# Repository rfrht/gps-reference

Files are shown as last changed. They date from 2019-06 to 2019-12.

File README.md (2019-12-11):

# GPS-Referenced Programmable Precision Signal Generator

**Current state:** Board built and operational! However, you will want to check [Issues](https://github.com/rfrht/gps-reference/issues)

**Next steps:** Fix issues and release a [Revision B](https://github.com/rfrht/gps-reference/tree/Experimental) - Already WIP.

## Overview

This is the do-it-yourself version of the u-Blox-based **GPS-Referenced Programmable Precision Signal Generator**.

The board design is largely inspired by [ZL2PD design](https://www.zl2pd.com/GPS_Freq_Ref.html) and features a few other stuff, like break-out headers for I2C, Serial, USB, External Battery and antenna selector. There are two signal outputs; one [DC-coupled (0-3.3V)](https://rf3.org:8443/q/gps/gps-ref-1-mhz.png), suitable for logic level output and an [AC-coupled (-1.6V - 1.6V)](https://rf3.org:8443/q/gps/gps-ref-dc-1-hz.png) output.

RA3APW [did some some extensive research (Russian content)](http://www.ra3apw.ru/proekty/ublox-neo-7m/) and found that there are a few frequencies where there is some very good precision for the general hobbyist, yielding precision between 0.1 PPM to 1 PPB. This is not a [GPS-Disciplined Oscillator](https://en.wikipedia.org/wiki/GPS_disciplined_oscillator) but a high precision [Numerically Controlled Oscillator](https://en.wikipedia.org/wiki/Numerically_controlled_oscillator) instead.

Bear in mind that the RA3APW tested U-Blox M-7 hardware, while in this project we will be using the newer generation [NEO-M8Q-01A Automotive grade](https://www.u-blox.com/en/product/neo-m8q-01a-module), which sports a [TCXO](https://en.wikipedia.org/wiki/Crystal_oscillator#Temperature), (hopefully) increasing precision.

## Frequencies

The tested high reliability frequencies are, namely:

| Frequency | Frequency |
| --- | --- |
| [300 kHz](https://rf3.org:8443/q/gps/gps-ref-300-khz.png) | [500 kHz](https://rf3.org:8443/q/gps/gps-ref-500-khz.png) |
| [1 MHz](https://rf3.org:8443/q/gps/gps-ref-1-mhz.png) | [1.2 MHz](https://rf3.org:8443/q/gps/gps-ref-1-2-mhz.png) |
| [1.5 MHz](https://rf3.org:8443/q/gps/gps-ref-1-5-mhz.png) | [1.6 MHz](https://rf3.org:8443/q/gps/gps-ref-1-6-mhz.png) |
| [2 MHz](https://rf3.org:8443/q/gps/gps-ref-2-mhz.png) | [2.4 MHz](https://rf3.org:8443/q/gps/gps-ref-2-4-mhz.png) |
| [3 MHz](https://rf3.org:8443/q/gps/gps-ref-3-mhz.png) | [4 MHz](https://rf3.org:8443/q/gps/gps-ref-4-mhz.png) |
| [4.8 MHz](https://rf3.org:8443/q/gps/gps-ref-4-8-mhz.png) | [6 MHz](https://rf3.org:8443/q/gps/gps-ref-6-mhz.png) |
| [8 MHz](https://rf3.org:8443/q/gps/gps-ref-8-mhz.png) | [12 MHz](https://rf3.org:8443/q/gps/gps-ref-12-mhz.png) |
| [24 MHz](https://rf3.org:8443/q/gps/gps-ref-24-mhz.png) | --- |

There are certainly others. It seem to follow some mathematical order, but I failed to figure out the proper sequence.

### Good frequency waveform
This is a 1 MHz waveform:

1 MHz GPS-Referenced signal

### Non-optimal frequencies
Check this 16 MHz signal, there are harmonics along the main waveform:

16 MHz unsuitable waveform

This is how the problem manifests in low frequencies. Check the falling edge of a 360 kHz:

360 kHz signal

## Configuration
Use the [U-Blox U-Center](https://www.u-blox.com/en/product/u-center) tool to configure your board. Open the Config page, in `TP5 (Timepulse 5)` menu and configure as per the below screenshot:

U-Blox Signal Generator configuration

*U-Blox Configuration page - Click to enlarge*

## Artefacts

The [schematics](/Schematics) are in Autodesk Eagle CAD format.

There is a [Gerber](https://github.com/rfrht/gps-reference/raw/master/Design/gps-gerbers.zip) for ordering a PCB from your favourite PCB shop (Hint: $2 in jlcpcb.com for 5 units), as well a Digi-Key friendly [Bill of Materials](/Design/gps-bom.csv), which currently costs around $27 (including the GPS module).

## Board pictures:
Board:

Board front

Cabled (with external wire antenna):
Cabled GPS Referenced Board

## TODO:
Check [Issues](https://github.com/rfrht/gps-reference/issues)

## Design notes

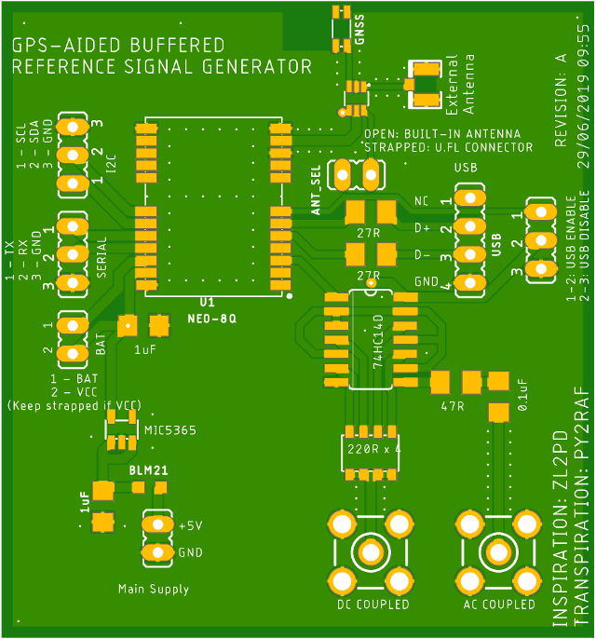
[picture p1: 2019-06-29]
Design/gps-top.png

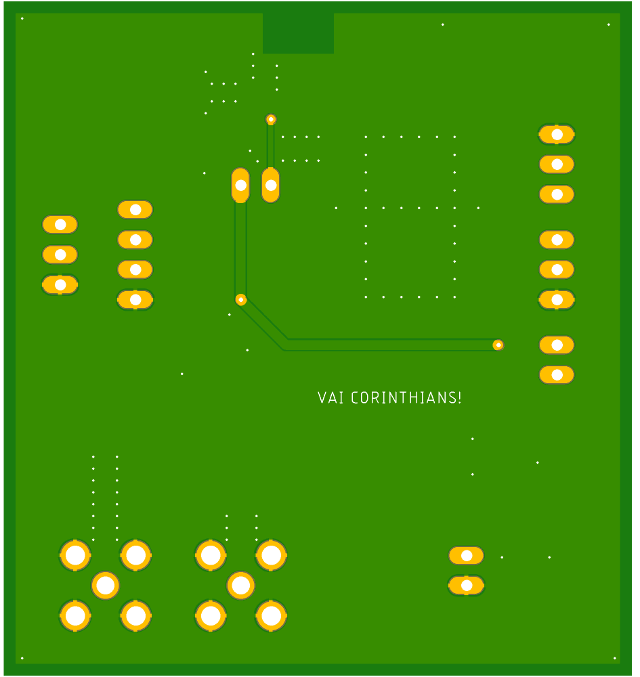
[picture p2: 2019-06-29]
Design/gps-bottom.png

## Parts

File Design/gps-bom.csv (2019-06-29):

Qty | Value | Device | Package | Parts | Digi-Key PN
1 | 0.1uF | C-EUC1206 | 1206 | C1 | 732-8086-1-ND
2 | 1uF | C-EUC1206 | 1206 | C2, C3 | 732-7685-1-ND
1 | 74HC14D | 74HC14D | SO14 | IC1 | 1727-1029-1-ND
1 | +5V | JP1E | JP1 | JP7 | S1012EC-40-ND
1 | BLM21 | L-USL2012C | L2012C | L1 | 490-1041-1-ND
1 | PE4259 | PE4259 | SC-70 | Q1 | 1046-1011-1-ND
1 | MIC5365 | MIC5365 | SOT23-5L | Q2 | 576-4085-1-ND
1 | 744C083 | 744C083 | 1206X4 | R1 | 744C083221JPCT-ND
1 | 47R | R-US_M1206 | 1206 | R2 | CR1206-FX-47R0ELFCT-ND
2 | 27R | R-US_M1206 | 1206 | R3, R4 | RHM27CJCT-ND
1 | NEO-8Q | NEO-8 | NEO | U1 | 672-1174-1-ND
2 | REF_DC | SMA-PCB | SMA-RF | X1, X2 | A97594-ND
1 | GNSS | ANT-GNSS-MLX | MOLEX-GNSS | X3 | WM16803CT-ND
1 | Ext Ant | ANTENNA_U.FL | U.FL | X4 | A118077CT-ND

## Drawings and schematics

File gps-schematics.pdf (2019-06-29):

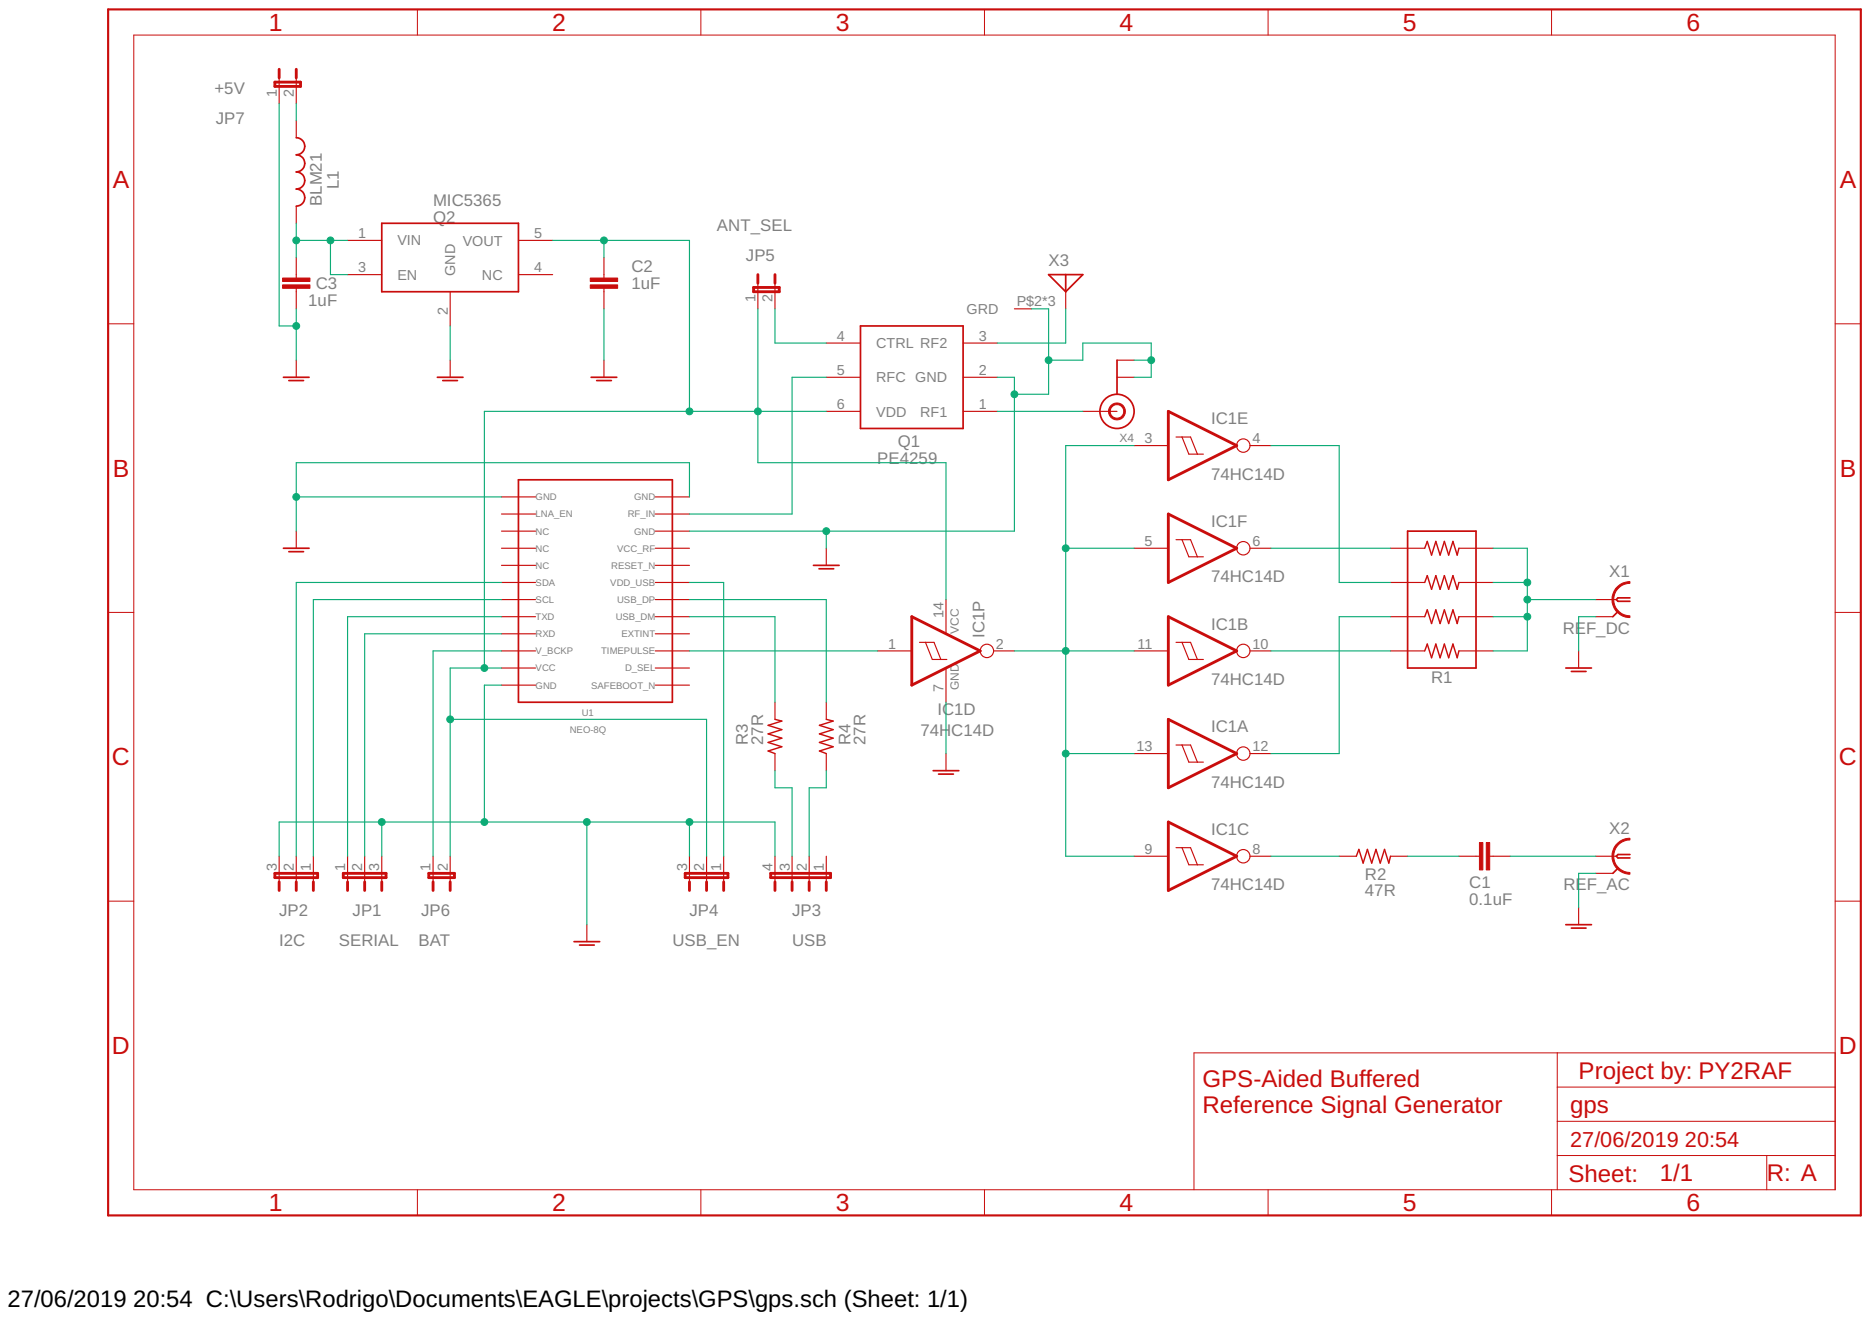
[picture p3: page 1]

27/06/2019 20:54 C:\Users\Rodrigo\Documents\EAGLE\projects\GPS\gps.sch (Sheet: 1/1)

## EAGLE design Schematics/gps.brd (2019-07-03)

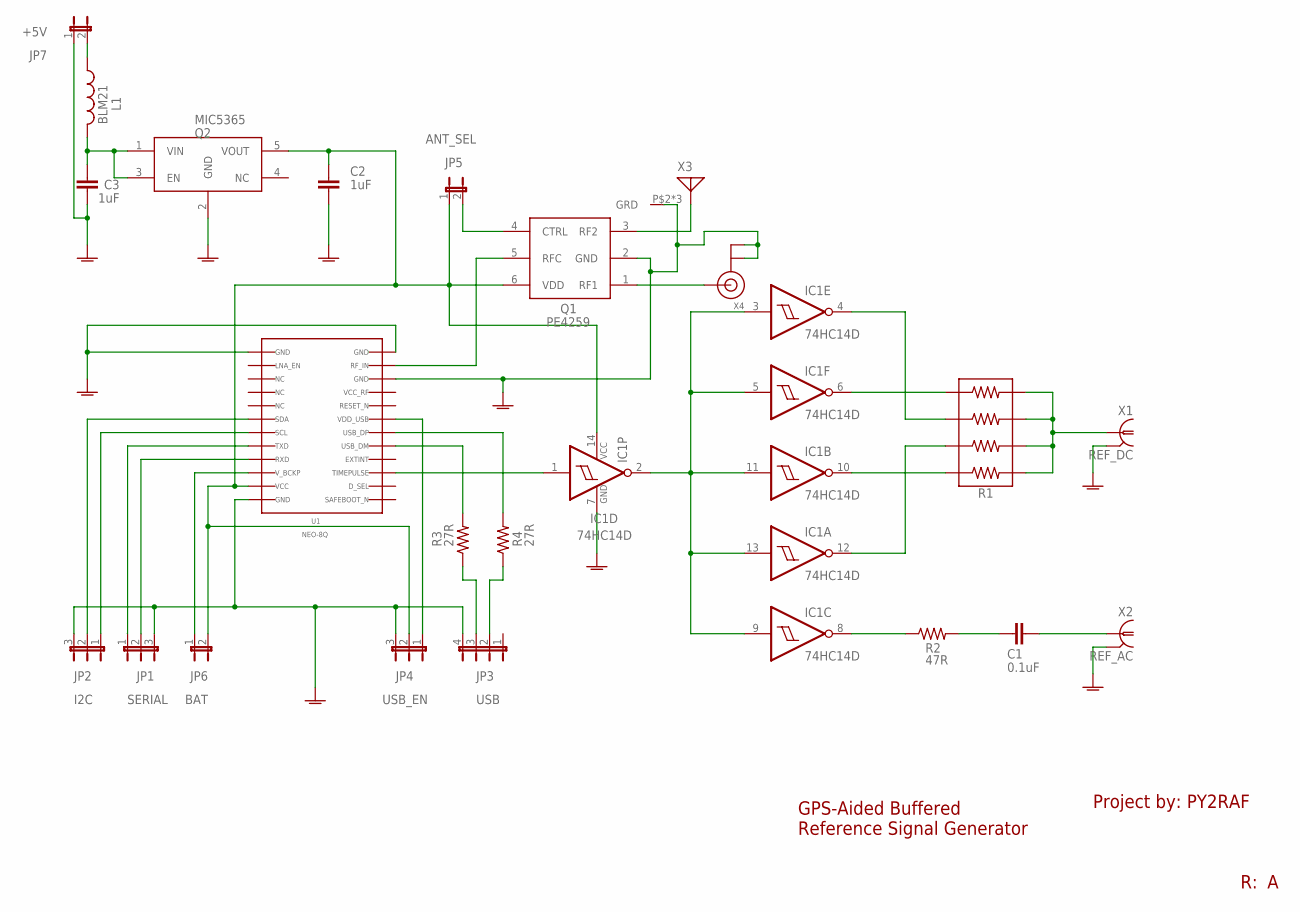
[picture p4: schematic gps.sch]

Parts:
C1: 0.1uF; C1206
C2, C3: 1uF; C1206
IC1: 74HC14D; SO14
JP1: SERIAL; JP2
JP2: I2C; JP2
JP3: USB; JP4
JP4: USB_EN; JP2
JP5: ANT_SEL; JP1
JP6: BAT; JP1
JP7: +5V; JP1
L1: BLM21; L2012C
Q1: PE4259; SC-70
Q2: MIC5365; SOT23-5L
R1: 744C083; 1206X4
R2: 47R; M1206
R3, R4: 27R; M1206
U1: NEO-8Q; NEO-7
X1: REF_DC; SMA-RF
X2: REF_AC; SMA-RF
X3: ANT-GNSS-MLX; MOLEX-GNSS
X4: ANTENNA_U.FL; U.FL

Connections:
GNDA: C2.2, C3.2, IC1.7 (GND), JP1.3, JP2.3, JP3.4, JP4.3, JP7.1, Q1.2 (GND), Q2.2 (GND), U1.10, U1.12, U1.13, U1.24, X1.2, X1.3 (2), X1.4 (2), X1.5 (2), X2.2, X2.3 (2), X2.4 (2), X2.5 (2), X3.P$2 (GRD), X3.P$3 (GRD), X3.P$4 (GRD), X4.1 (GND), X4.2 (GND)
unnamed: IC1.2 (O), IC1.3 (I), IC1.5 (I), IC1.9 (I), IC1.11 (I), IC1.13 (I)
unnamed: IC1.4 (O), R1.P$3 (3)
unnamed: IC1.12 (O), R1.P$2 (2)
unnamed: IC1.10 (O), R1.P$1 (1)
unnamed: IC1.6 (O), R1.P$4 (4)
unnamed: IC1.1 (I), U1.3
unnamed: IC1.8 (O), R2.1
unnamed: C1.2, R2.2
unnamed: R3.2, U1.5
unnamed: R4.2, U1.6
unnamed: C1.1, X2.1
unnamed: JP4.1, U1.7
unnamed: JP3.3, R3.1
unnamed: JP3.2, R4.1
unnamed: JP2.2, U1.18
unnamed: JP2.1, U1.19
unnamed: JP1.2, U1.21
unnamed: JP1.1, U1.20
unnamed: JP6.1, U1.22
unnamed: JP5.2, Q1.4 (CTRL)
unnamed: R1.P$5 (5), R1.P$6 (6), R1.P$7 (7), R1.P$8 (8), X1.1
unnamed: C2.1, IC1.14 (VCC), JP4.2, JP5.1, JP6.2, Q1.6 (VDD), Q2.5 (VOUT), U1.23
unnamed: Q1.5 (RFC), U1.11
unnamed: C3.1, L1.2, Q2.1 (VIN), Q2.3 (EN)
unnamed: JP7.2, L1.1
unnamed: Q1.3 (RF2), X3.P$1 (ANT)
unnamed: Q1.1 (RF1), X4.3 (SIGNAL)

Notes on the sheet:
GPS-Aided Buffered Reference Signal Generator
Project by:

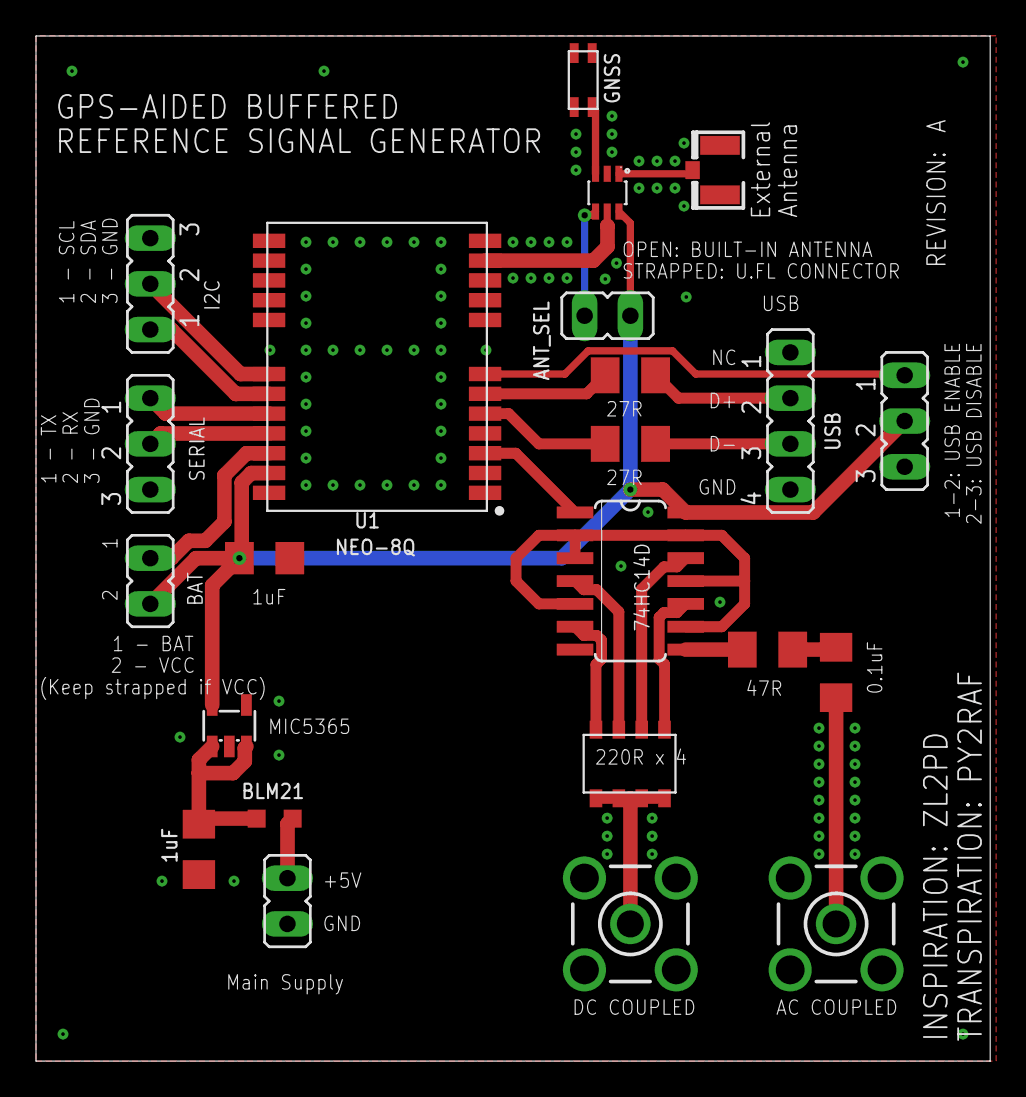
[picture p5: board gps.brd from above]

Board: 2 copper layers, 53.0 x 57.0 mm, 23 parts (0 on the bottom side), 28 nets.

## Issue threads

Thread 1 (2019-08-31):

Wrong antenna solder pad

rfrht, 2019-08-31:
**ISSUE**
The antenna solder pad is PLAIN WRONG.

**ENVIRONMENT**

**SOLUTION**
The definitive solution will involve a new board revision with the corrected solder pad
As a workaround, use the U.FL connector.

rfrht, 2019-12-10:
Fixed in Rev. B

Closed 2019-12-10.

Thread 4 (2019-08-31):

Make a switchable USB powering

rfrht, 2019-08-31:
Currently, the +5V from USB cable ends in a N/C lead.

Connect this lead to a jumper switch selecting the board power.

rfrht, 2019-12-10:
Implemented in Rev. B

Closed 2019-12-10.

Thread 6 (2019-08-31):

Add a frequency LED

rfrht, 2019-08-31:

rfrht, 2019-12-10:
Not happening - The GPS signal is fed to the Clock generator and I don't want to disturb the signal potentially adding jittery.

Closed 2019-12-10.

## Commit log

2019-06-29 Revision A
    Initial commit
    [gps-bom.csv, gps.brd, gps.sch]
2019-07-03 Straightened a Serial port Route
    [gps.brd]
